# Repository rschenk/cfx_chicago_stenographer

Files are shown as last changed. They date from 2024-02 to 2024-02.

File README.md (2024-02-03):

<!-- omit from toc -->
# Chicago Stenographer Keycaps - Optimized for JLCPCB 3D printing

### The purpose of this fork

This fork resizes the Chicago Stenographer keycaps to be the same size as the quirky Chosfox CFX keycaps (16.5x16.5mm). The original CS keycaps are the standard "choc size" of 17.5x16.5mm, so the keycaps in this fork are 1mm narrower in width. 

Why? Because I designed my [Tern keyboard](https://github.com/rschenk/tern) spaced for CFX keycaps, mostly because I had them lying around and why not. Now I love that keyboard and wanted some Chicago Steno caps for it.

### Prior forks

This is forked from [infused-kim/kb_keycaps_chicago_stenographer](https://github.com/infused-kim/kb_keycaps_chicago_stenographer), which combines multiple chicago stenographer keycaps with sprues into one file to get around the $1 minimum charge of JLCPCB.

If you like these keycaps after trying the 3D printed version, [consider buying original versions from the creator at asymplex.xyz](https://www.asymplex.xyz).

### Printing at JLC

I have successfully printed multiple batches of these keycaps at JLC using the MJF process described below and they came out good. One batch, the stems were a little bit oversized, but a few scrapes with an X-Acto knife and they fit in the switches perfectly. The other batches fit great right out of the box. I'm typing on them right now.

<!-- omit from toc -->
## Table Of Contents

1. [Photos](#photos)
    1. [Render](#render)
    2. [Real Life](#real-life)
2. [About this fork](#about-this-fork)
3. [Documentation](#documentation)
    1. [Keycap Types](#keycap-types)
        1. [R2 Keycaps - Top](#r2-keycaps---top)
        2. [R3 Keycaps - Middle rows and home row](#r3-keycaps---middle-rows-and-home-row)
        3. [R4 Keycaps - Bottom](#r4-keycaps---bottom)
        4. [Thumb Keycaps](#thumb-keycaps)
        5. [1.5u Thumb Key](#15u-thumb-key)
        6. [Convex Keycaps](#convex-keycaps)
        7. [Lateral Keycaps](#lateral-keycaps)
    2. [What to print...](#what-to-print)
        1. [If you have a 5x3 row board (Such as the corne without the outer coulmn)](#if-you-have-a-5x3-row-board-such-as-the-corne-without-the-outer-coulmn)
        2. [If you have a 6x3 row board (Such as the corne WITH the outer coulmn)](#if-you-have-a-6x3-row-board-such-as-the-corne-with-the-outer-coulmn)
        3. [If you have a 6x4 board with a num row...](#if-you-have-a-6x4-board-with-a-num-row)
    3. [How to order on JLCPCB](#how-to-order-on-jlcpcb)
        1. [JLCPCB Shopping Cart Example](#jlcpcb-shopping-cart-example)
    4. [How to create custom sets of keycaps](#how-to-create-custom-sets-of-keycaps)

## Photos

### Render

Subtly sculpted choc spaced low profile
CS

### Real Life

This photo is from the creator's repo. It's not a JLCPCB print.

Look

## About this fork

This is a fork of [sporkus/PseudoMakeMeKeyCapProfiles](https://github.com/sporkus/PseudoMakeMeKeyCapProfiles/), which is a fork of [pseudoku's original chicago stenographer keycaps](https://github.com/pseudoku/PseudoMakeMeKeyCapProfiles).

Sporkus is the one who came up with the idea and the code to add spuers to the keycaps.

I expanded on those efforts in the following ways...

* Added support to generate rows of varying keycaps
* Fixed the 1.5u inner thumb key that is used in many corne-like boards
* Added the homing bar option to the lateral keys
* Added documentation on how to print the keycaps
* Fixed openscad warnings

Screenshot of thumbs stl

## Documentation

### Keycap Types

When I first started looking into these keycaps, I was incredibly confused by all the available keycap variations and files.

This repo is my attempt to simplify and document what I learned.

In the MX keycap world Rx is used to refer to rows and keycap heights. As someone who was only using Choc keycaps in the ergo keyboard world that was not intuitive for me at all.

But this graphic [from melgeek](https://www.melgeek.com/blogs/guide/the-type-of-keycaps-profiles) explains it well:
Keycap Rows

#### R2 Keycaps - Top

You use these keycaps for the top row, but for the CS keycap set, both R2 and R4 are the same. You simply flip them around.

I also included pre-rotated keycaps as R4, but you can also just print R2 twice.

If your keyboard has a num row, you would use them for the num row and the bottom alpha row.

If you have a corne-style keyboard with just three rows, you would use it for the top and bottom alpha rows.

#### R3 Keycaps - Middle rows and home row

You use these keycaps for the columns between the top and bottom rows.

If you have a num row, you would use it for the top alpha row and the homerow.

If you have a corne-style keyboard with just three rows, you would use it just for the home row.

#### R4 Keycaps - Bottom

As explained in the R2 section, these are exactly the same as the R2 files, but pre-rotated.

You can order 2x R2 or 1x R2 + 1x R4.

#### Thumb Keycaps

The thumb keycaps are designed to create a "dish" with ridges on the outer thumb keys.

The same model is used for the left and right keys, but it is mirrored. In this repo you will find a model that already has all the versions you will need.

If you have a corne-style thumb cluster with 3 keys, you can use a convex key for the middle one. It will act like a homing key.

And there is an alternative convex key included, which is slightly lower so that you can see which one you like better.

#### 1.5u Thumb Key

Additionally, there are also 1.5u variations of the outer thumb keys.

You have to be very careful if you get the files from other repos, because by default the stem is rotated by 90 degrees unlike regular 1.5u keys.

The files here have the stem in the correct orientation for keyboards like the corne where the switch is already rotated by 90 degrees.

#### Convex Keycaps

The convex keys are used on the middle thumb keys, but can also optionally be used on the inner and outer columns.

You can [see an example of how that looks here](https://www.printables.com/model/158865-chicago-steno-low-profile-ergo-keycaps).

#### Lateral Keycaps

Steno keycaps have vertical ridges that keep your finger aligned in the row. This is great, but some people prefer to not have these ridges for the inner and outer columns so that they don't have to lift the finger to reach the side-key or to perform horizontal combos with one finger.

Keep in mind, that the lateral keycaps are used as a pair on two columns next to each other.

The file contains only one set of the two. If you want it on both sides of the keyboard, you have to print it twice.

I suggest printing one version with the homing dots and another with the homing bars to get all possible variations.

### What to print...

You can find all files in the stl directory. You can also look at the `export_cs_*.scad` files to see what key models were used and further comments on how to use the sets.

#### If you have a 5x3 row board (Such as the corne without the outer coulmn)

* 1x `cs_row_r2_top.stl`
* 1x `cs_row_r3_homerow_bar.stl` or `cs_row_r3_homerow_dots.stl` (different homing keys)
  * Or the `cs_row_r3_regular.stl` and `cs_row_r3_homing_only.stl` to get both homing key variations
* 1x `cs_row_r4_bottom.stl`
* 1x `cs_row_thumbs.stl`

#### If you have a 6x3 row board (Such as the corne WITH the outer coulmn)

All of the above, PLUS...

* 1x `cs_column_regular.stl` or `cs_column_convex.stl` for the outer pinky column

You can also print the `cs_column_regular_with_homing_bars.stl` variation which contains two more homing key.

Combine it with the `cs_row_r3_homerow_dots.scad` to get both homing key variations without needing to print them separately.

Alternatively, you can also consider the lateral variation, but this one needs to be printed twice as it should be used on both the outer and pinky keys.

The leeve rows can also be used for the index and inner column as the stl includes homing key variations.

To be able to use lateral keys on both sides and get both types of homing keys you should print...

* 1x `cs_column_lateral_homing_bar.stl`
* 1x `cs_column_lateral_homing_dot.stl`

#### If you have a 6x4 board with a num row...

All of the above, PLUS...

* 1x `cs_row_r3_regular.stl` for the top alpha row (the r2 keycaps will be used for the num row)

### How to order on JLCPCB

* Upload the stl model
* Select 3D Technology: `MJF (Nylon)`
* Select Material: `PA12-HP Nylon`
* Optionally select Surface Finish: `Add - Dyeing - Dyed Black` to get black keycaps.
  * Without this they will be a "textured gray"
* Make sure to select the correct Quantity

The total for a 6x4 board with all the optional stuff will cost $23.88 + shipping.

> **Warning**
> You will likely get warnings that some areas on the 1.5u thumb keys are too thin.
>
> The original code for the 1.5u thumb keys produced keycaps with the wrong stem orientation. I have attempted to fix this problem, but JLCPCB still complains about areas that are too thin and will ask you if you want to take the risk of them not getting printed correctly when you order.
>
> All other keycaps should not have problems though.
>
> I have accepted the risk and will update this message once I receive the keycaps.

#### JLCPCB Shopping Cart Example

JLCPCB Shopping Cart Example

### How to create custom sets of keycaps

* Install OpenSCAD
  * The [snaphot version](https://openscad.org/downloads.html#snapshots) is recommended for performance reasons
  * If it crashes, [try an older version of the snapshot](https://files.openscad.org/snapshots/)
* Set up the dev environment
  * Adjust the Makefile with the path to your OpenSCAD installation
  * Unzip the `libraries.zip` into your [OpenSCAD library path](https://en.wikibooks.org/wiki/OpenSCAD_User_Manual/Libraries)
* Create your keycap set
  * Copy one of the files starting with `export_`
  * Adjust the keycaps you want to use. Available options are in `gen_sprued_keycaps.scad`
  * Keep in mind that jlcpcb only allows a maximum of 10 keycaps per file
* Generate STLs
  * Run `make` and it will generate all missing STLs
  * Alternatively you can also select which file to generate by running something like `make stl/cs_row_thumbs.stl`, but keep in mind that you have to use the file name of the final stl file and not of the source `.scad` file

Alternatively you can also run the GUI version, but it's a bit slow.

You can speed it up by enabling the `manifold` options in `Preferences -> Features` (Snapshot version only).

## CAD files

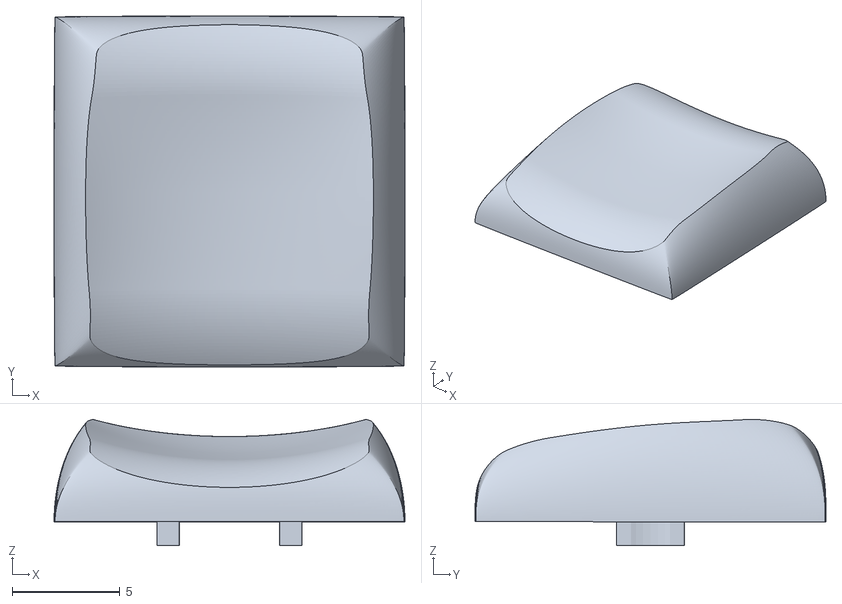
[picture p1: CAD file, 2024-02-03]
stl/single_keys/cs_r2_1.stl
16.3 x 16.3 x 5.86

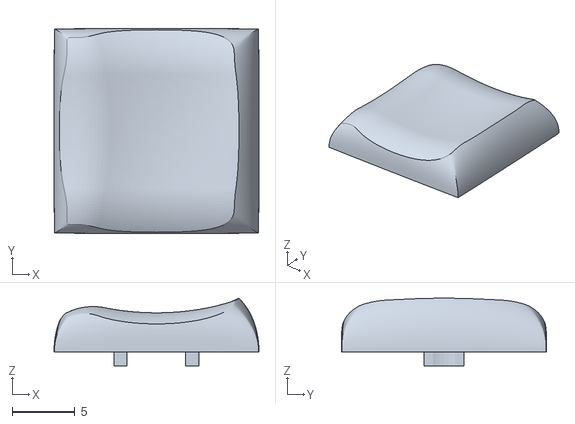
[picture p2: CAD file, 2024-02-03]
stl/single_keys/cs_r3_lateral_r.stl
16.3 x 16.3 x 5.38

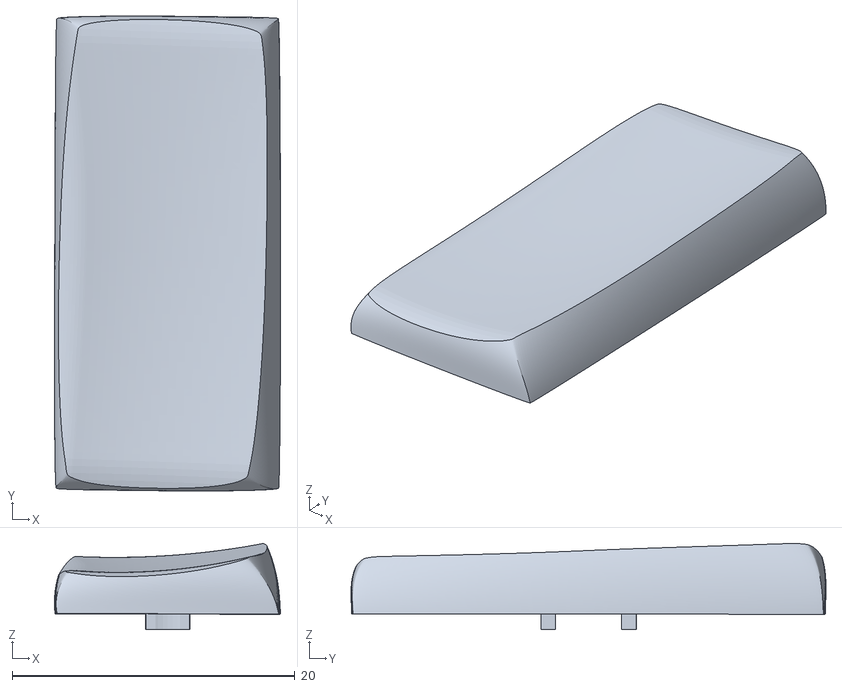
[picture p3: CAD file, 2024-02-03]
stl/single_keys/cs_t_2_r.stl
16.0 x 33.6 x 6.08

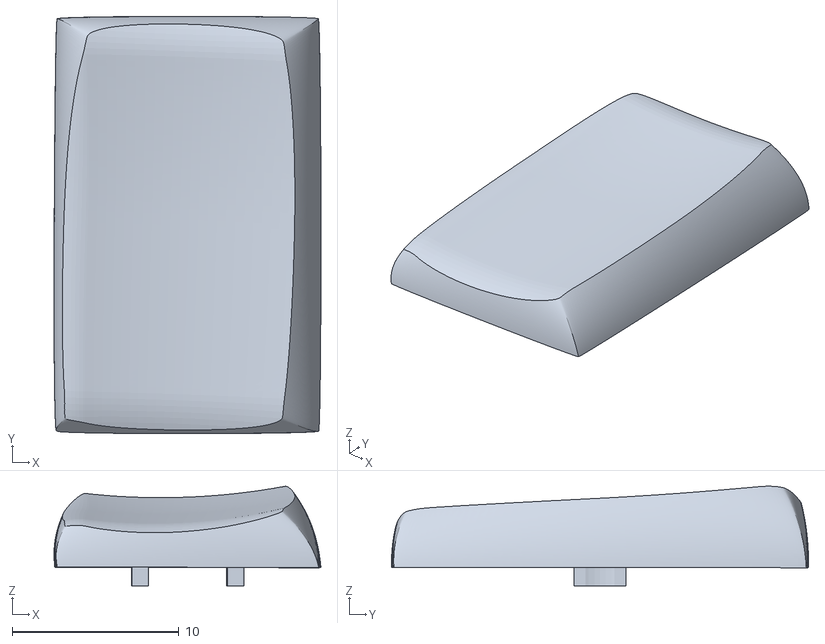
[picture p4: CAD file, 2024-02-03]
stl/single_keys/cs_t_stem_rot_15_r.stl
16.0 x 25.0 x 5.97

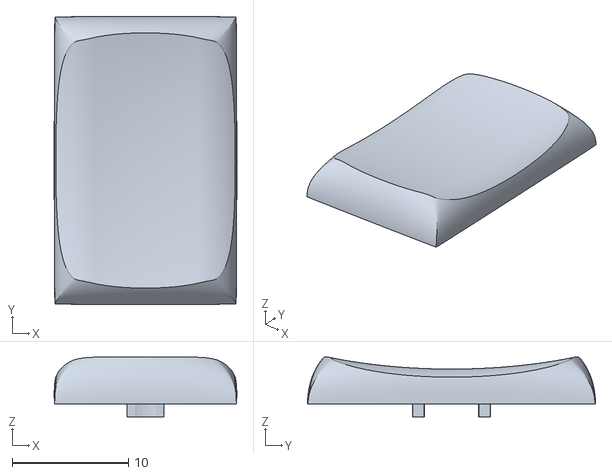
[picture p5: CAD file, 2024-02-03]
stl/single_keys/cs_r3_15.stl
15.7 x 24.8 x 5.15

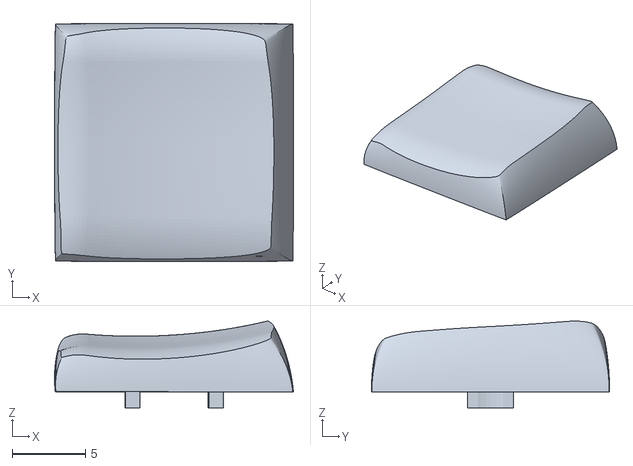
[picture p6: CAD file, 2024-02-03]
stl/single_keys/cs_t_1_r.stl
16.4 x 16.3 x 5.95

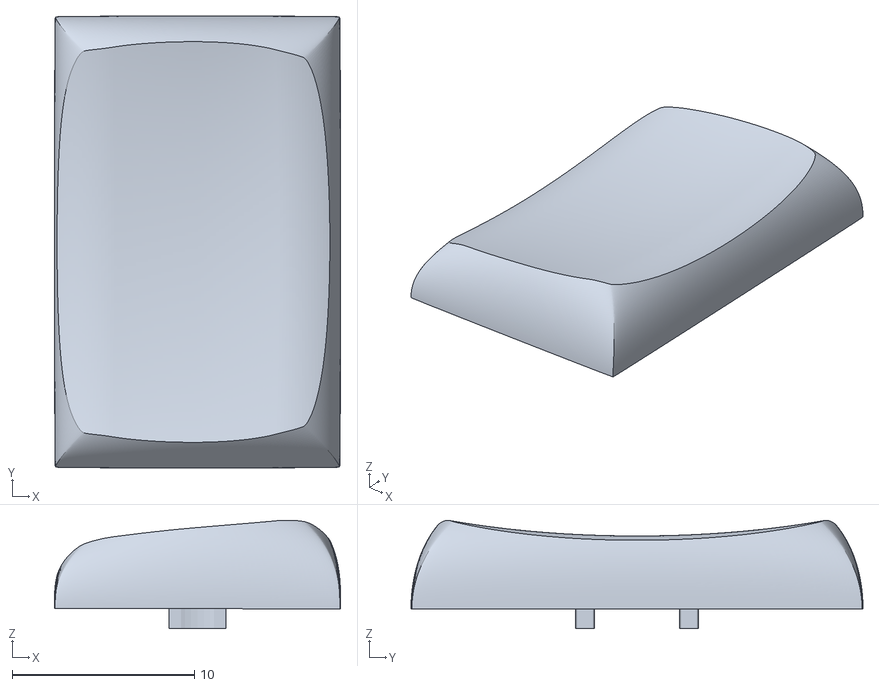
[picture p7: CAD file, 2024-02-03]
stl/single_keys/cs_r2_15.stl
15.7 x 24.8 x 5.95

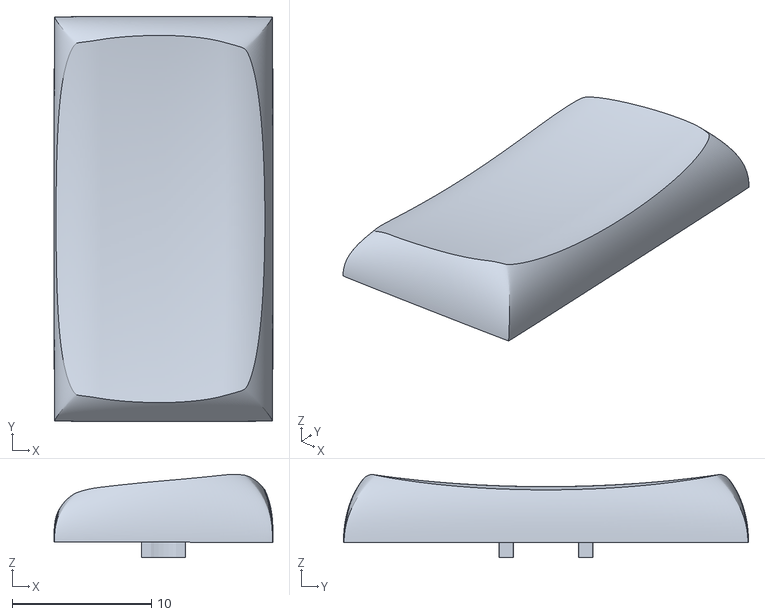
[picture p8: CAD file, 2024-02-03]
stl/single_keys/cs_r2_175.stl
15.7 x 29.0 x 5.96

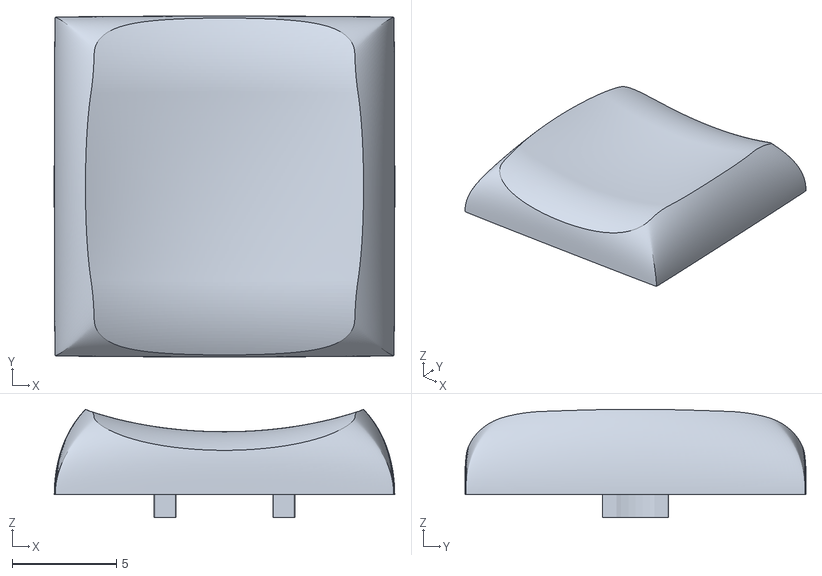
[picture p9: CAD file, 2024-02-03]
stl/single_keys/cs_r3_1.stl
16.3 x 16.3 x 5.19

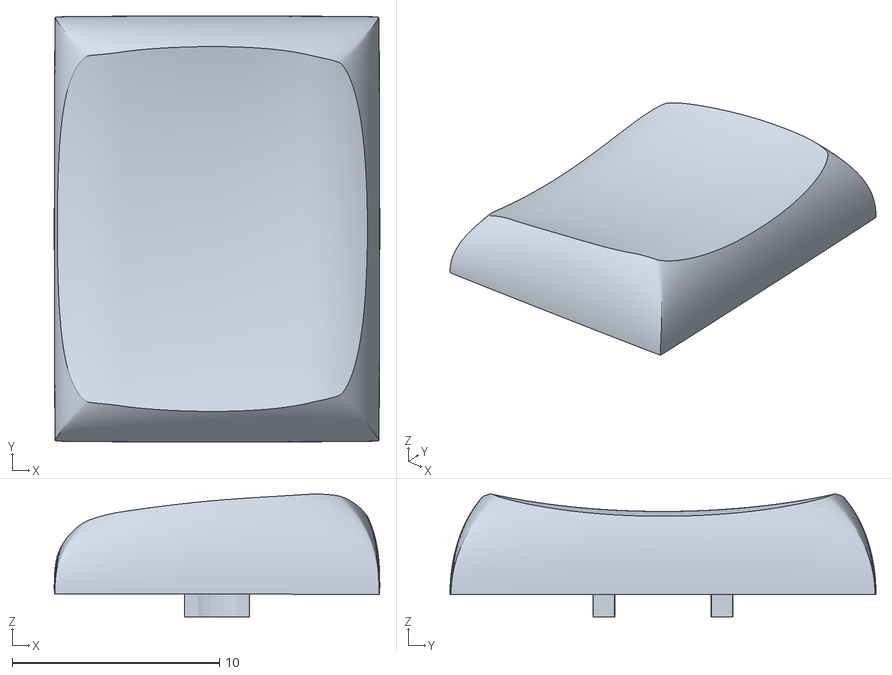
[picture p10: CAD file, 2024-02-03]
stl/single_keys/cs_r2_125.stl
15.7 x 20.5 x 5.93

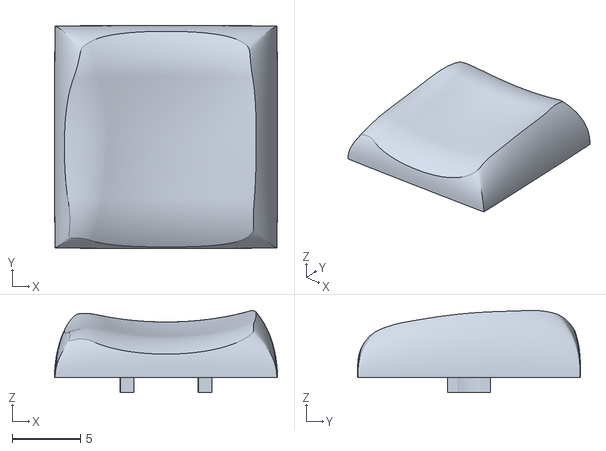
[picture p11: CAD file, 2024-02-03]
stl/single_keys/cs_r2_lateral_r.stl
16.3 x 16.3 x 6.01

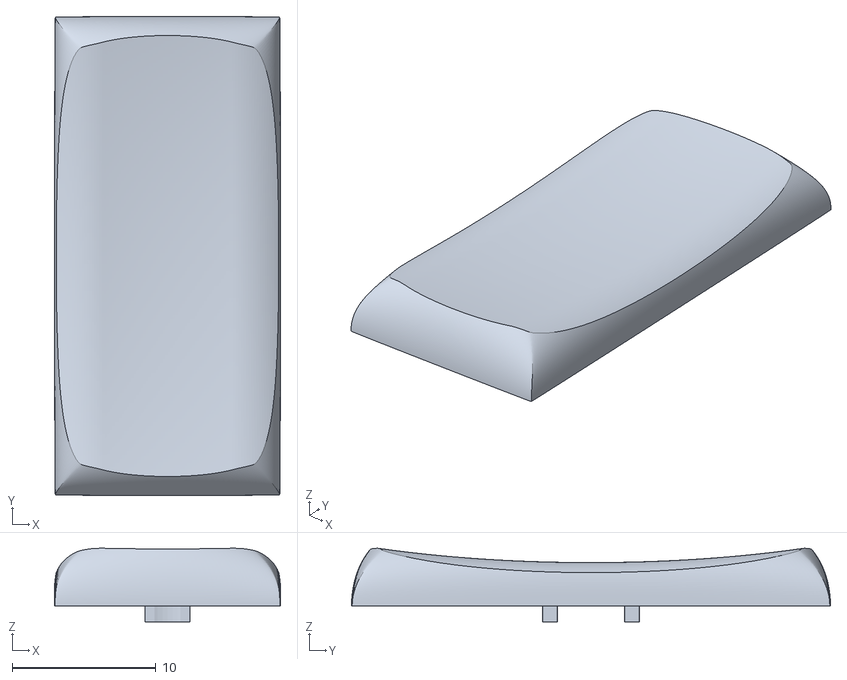
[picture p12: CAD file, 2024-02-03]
stl/single_keys/cs_r3_2.stl
15.7 x 33.3 x 5.12

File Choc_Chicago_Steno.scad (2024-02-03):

use <scad-utils/morphology.scad> //for cheaper minwoski
use <scad-utils/transformations.scad>
use <scad-utils/shapes.scad>
use <scad-utils/trajectory.scad>
use <scad-utils/trajectory_path.scad>
use <sweep.scad>
use <skin.scad>
//use <z-butt.scad>

//Choc Chord version Chicago Stenographer

/*Tester */
keycap_cs(
  keyID  = 6, //change profile refer to KeyParameters Struct
  cutLen = 0, //Don't change. for chopped caps
  Stem   = true, //tusn on shell and stems
  StemRot = 0, //change stem orientation by deg
  Dish   = true, //turn on dish cut
  Stab   = 0,
  visualizeDish = false, // turn on debug visual of Dish
  crossSection  = false, // center cut to check internal
  homeDot = false, //turn on homedots,
  homeBar = true, //turn on homebar,
  Legends = false
  );

//-Parameters
wallthickness = 1.1; // 1.75 for mx size, 1.1
topthickness = 3.0; //2 for phat 3 for chicago
stepsize = 50;  //resolution of Trajectory
step = 0.5;       //resolution of ellipes
fn = 60;          //resolution of Rounded Rectangles: 60 for output
layers = 50;    //resolution of vertical Sweep: 50 for output

//---Stem param
slop    = 0.3;
stemRot = 0;
stemWid = 8;
stemLen = 6;
stemCrossHeight = 1.8;
extra_vertical = 0.6;
stemLayers = 50; //resolution of stem to cap top transition
//#cube([18.16, 18.16, 10], center = true); // sanity check border

//injection param
draftAngle = 0; //degree  note:Stem Only
//TODO: Add wall thickness transition?


keyParameters = //keyParameters[KeyID][ParameterID]
[
//  BotWid, BotLen, TWDif, TLDif, keyh, WSft, LSft  XSkew, YSkew, ZSkew, WEx, LEx, CapR0i, CapR0f, CapR1i, CapR1f, CapREx, StemEx
    //Column 0
    //Levee: Chicago in choc Dimension
    [16.20,  16.20,   5.6, 	   5,  4.9,    0,   .0,     5,    -0,    -0,   2, 2.5,    .10,      2,     .10,      3,     2,       2], //Chicago Steno R2/R4
    [16.20,  16.20,   5.6, 	   5,  4.5,    0,   .0,     0,    -0,    -0,   2, 2.5,    .10,      3,     .10,      3,     2,       2], //Chicago Steno R3 flat
    [16.20,  16.20,  1.25, 	1.25,  4.5,    0,   .0,     0,    -0,    -0,   2, 2.5,    .10,     .5,     .10,     .5,     2,       2], //Chicago Steno R3 chord
    //mods 3
    [16.20,  16.20,  4.25, 	3.25,  5.5,  -.7,  0.7,     0,    -4,    -0,   2,   2,    .10,      2,     .10,      2,     2,       2], //Levee Corner R2
    [16.20,  16.20,  4.25, 	3.25,  5.2,  -.8,  0.6,     0,    -4,    -0,   2,   3,    .10,      2,     .10,      2,     2,       2], //Levee Corner R2
    //1.25: [5, 6]
    [20.45,  15.60,  5.6, 	   5,  4.9,    0,   .0,     5,    -0,    -0,   2, 2.5,     .1,      2,      .1,      3,     2,       2], //Chicago Steno R2/R4 1.25u
    [20.45,  15.60,  5.6, 	   5,  4.5,    0,   .0,     0,    -0,    -0,   2, 2.5,     .1,      3,      .1,      3,     2,       2], //Chicago Steno R3 1.25u
    //1.5: [7, 8]
    [24.70,  15.60,   5.6, 	   5,  4.9,    0,   .0,     5,    -0,    -0,   2, 2.5,     .1,      2,      .1,      3,     2,       2], //Chicago Steno R2/R4 1.5
    [24.70,  15.60,   5.6, 	   5,  4.5,    0,   .0,     0,    -0,    -0,   2, 2.5,     .1,      3,      .1,      3,     2,       2], //Chicago Steno R3 1.5u
    //1.75: [9, 10]
    [28.95,  15.60,   5.6, 	   5,  4.9,    0,   .0,     5,    -0,    -0,   2, 2.5,     .1,      2,      .1,      3,     2,       2], //Chicago Steno R2/R4 1.5
    [28.95,  15.60,   5.6, 	   5,  4.5,    0,   .0,     0,    -0,    -0,   2, 2.5,     .1,      3,      .1,      3,     2,       2], //Chicago Steno R3 1.5u
    //2.00: [11, 12]
    [33.20,  15.60,   5.6, 	   5,  4.9,    0,   .0,     5,    -0,    -0,   2, 2.5,     .1,      2,      .1,      3,     2,       2], //Chicago Steno R2/R4 1.5
    [33.20,  15.60,   5.6, 	   5,  4.5,    0,   .0,     0,    -0,    -0,   2, 2.5,     .1,      3,      .1,      3,     2,       2], //Chicago Steno R3 1.5u
    //2.25: [13, 14]
    [37.45,  15.60,   5.6, 	   5,  4.9,    0,   .0,     5,    -0,    -0,   2, 2.5,     .1,      2,      .1,      3,     2,       2], //Chicago Steno R2/R4 1.5
    [37.45,  15.60,   5.6, 	   5,  4.5,    0,   .0,     0,    -0,    -0,   2, 2.5,     .1,      3,      .1,      3,     2,       2], //Chicago Steno R3 1.5u
    // Ergo shits
    [18.75,  18.75,   5.6, 	   5,    8,    0,   .25,     0,    -0,    -0,   2, 2.5,    .10,      3,     .10,      3,     2,       2], //highpro 19.05 R2|4
    [17.20,  16.00,   5.6, 	   5,  4.7,    0,   .0,      3,    -0,    -0,   2, 2.5,    .10,      2,     .10,      3,     2,       2], //Chicago Steno R2 ALT
    [17.20,  16.00,   5.6, 	   5,  5.5,    0,   .0,      7,    -0,    -0,   2, 2.5,    .10,      2,     .10,      3,     2,       2], //Chicago Steno R1 Steap
    [17.20,  16.00,   5.6, 	   5,  7.0,    0,   .0,     10,    -0,    -0,   2, 2.5,    .10,      2,     .10,      3,     2,       2] //Chicago Steno R1 mild with alt R2
];

dishParameters = //dishParameter[keyID][ParameterID]
[
//FFwd1 FFwd2 FPit1 FPit2  DshDep DshHDif FArcIn FArcFn FArcEx     BFwd1 BFwd2 BPit1 BPit2  BArcIn BArcFn BArcEx
  //Column 0
  [ 4.5,    4,    7,  -50,      7,    1.7,   11.5,    17.5,     2,      4.5,    4,    2,   -35,   11.5,  15,     2], //Chicago Steno R2/R4
  [ 4.5,    4,    5,  -40,      7,    1.7,   11.5,    15,     2,      4.5,    4,    5,   -40,   11.5,    15,     2], //Chicago Steno R3 flat
  [ 4.5,    4,    5,  -40,      7,    1.7,   11.5,    15,     2,      4.5,    4,    5,   -40,   11.5,    15,     2], //Chicago Steno R3 chord

  [   6,  3.5,    7,  -50,      5,    1.0,   16,    23,     2,        6,  3.5,    7,   -50,   16,    23,     2], //Levee Steno R2/R4
  [   6,  3.5,    7,  -50,      5,    1.0,   16,    23,     2,        6,  3.5,    7,   -50,   16,    23,     2], //Levee Steno R2/R4
  //1.25
  [ 4.5,    4,    7,  -40,      8,    1.7,   16.0,  22.5,     2,      4.5,    4,    2,   -35,   16.0,  19.5,     2], //Chicago Steno R2/R4
  [ 4.5,    4,    5,  -40,      8,    1.7,   16.0,  19.5,     2,      4.5,    4,    5,   -40,   16.0,  19.5,     2], //Chicago Steno R3
  //1.5
  [ 4.5,    4,    7,  -40,      8,    1.7,   20.5,  26.5,     2,      4.5,    4,    2,   -35,   20.5,  24.0,     2], //Chicago Steno R2/R4
  [ 4.5,    4,    5,  -40,      8,    1.7,   20.5,  24.0,     2,      4.5,    4,    5,   -40,   20.5,  24.0,     2], //Chicago Steno R3
  //1.75
  [ 4.5,    4,    7,  -40,      8,    1.7,   25.0,  31.0,     2,      4.5,    4,    2,   -35,   25.0,  28.5,     2], //Chicago Steno R2/R4
  [ 4.5,    4,    5,  -40,      8,    1.7,   25.0,  28.5,     2,      4.5,    4,    5,   -40,   25.0,  28.5,     2], //Chicago Steno R3
  //2.00
  [ 4.5,    4,    7,  -40,      8,    1.7,   29.5,  35.5,     2,      4.5,    4,    2,   -35,   29.5,  33.0,     2], //Chicago Steno R2/R4
  [ 4.5,    4,    5,  -40,      8,    1.7,   29.5,  33.0,     2,      4.5,    4,    5,   -40,   29.5,  33.0,     2], //Chicago Steno R3
  //2.25
  [ 4.5,    4,    7,  -40,      8,    1.7,   33.0,  39.0,     2,      4.5,    4,    2,   -35,   33.0,  36.5,     2], //Chicago Steno R2/R4
  [ 4.5,    4,    5,  -40,      8,    1.7,   33.0,  36.5,     2,      4.5,    4,    5,   -40,   33.0,  36.5,     2], //Chicago Steno R3

  [   5,    5,    5,  -40,      7,    1.7,   11,    15,     2,        5,    5,    5,   -40,   11,    15,     2], //Chicago Steno R3 flat
  [ 4.5,    4,    7,  -50,      7,    1.7,   11,    17,     2,      4.5,    4,    2,   -35,   11,    15,     2], //Chicago Steno R1
  [ 4.5,    4,    7,  -50,      7,    1.7,   11,    17,     2,      4.5,    4,    2,   -35,   11,    15,     2], //Chicago Steno R1
  [ 4.5,    4,    7,  -50,      7,    1.7,   11,    17,     2,      4.5,    4,    2,   -35,   11,    15,     2] //Chicago Steno R1
];


function BottomWidth(keyID)  = keyParameters[keyID][0];  //
function BottomLength(keyID) = keyParameters[keyID][1];  //
function TopWidthDiff(keyID) = keyParameters[keyID][2];  //
function TopLenDiff(keyID)   = keyParameters[keyID][3];  //
function KeyHeight(keyID)    = keyParameters[keyID][4];  //
function TopWidShift(keyID)  = keyParameters[keyID][5];
function TopLenShift(keyID)  = keyParameters[keyID][6];
function XAngleSkew(keyID)   = keyParameters[keyID][7];
function YAngleSkew(keyID)   = keyParameters[keyID][8];
function ZAngleSkew(keyID)   = keyParameters[keyID][9];
function WidExponent(keyID)  = keyParameters[keyID][10];
function LenExponent(keyID)  = keyParameters[keyID][11];
function CapRound0i(keyID)   = keyParameters[keyID][12];
function CapRound0f(keyID)   = keyParameters[keyID][13];
function CapRound1i(keyID)   = keyParameters[keyID][14];
function CapRound1f(keyID)   = keyParameters[keyID][15];
function ChamExponent(keyID) = keyParameters[keyID][16];
function StemExponent(keyID) = keyParameters[keyID][17];
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

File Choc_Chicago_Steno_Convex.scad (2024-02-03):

use <scad-utils/morphology.scad> //for cheaper minwoski
use <scad-utils/transformations.scad>
use <scad-utils/shapes.scad>
use <scad-utils/trajectory.scad>
use <scad-utils/trajectory_path.scad>
use <sweep.scad>
use <skin.scad>
//use <z-butt.scad>

//NOTE: with sweep cuts, top surface may not be visible in review, it should be visible once rendered

mirror([0,0,0])keycap_cs_convex(
  keyID  = 2, //change profile refer to KeyParameters Struct
  cutLen = 0, //Don't change. for chopped caps
  Stem   = true, //tusn on shell and stems
  StemRot = 0,//change stem orientation by deg
  Dish   = true, //turn on dish cut
  Stab   = 0,
  visualizeDish = true, // turn on debug visual of Dish
  crossSection  = false, // center cut to check internal
  homeDot = false, //turn on homedots
  Legends = false
);

//Parameters
wallthickness = 1.2;
topthickness  = 2;   //
stepsize      = 50;  //resolution of Trajectory
step          = 1;   //resolution of ellipes
fn            = 60;  //resolution of Rounded Rectangles: 60 for output
layers        = 50;  //resolution of vertical Sweep: 50 for output
dotRadius     = 1.25;   //home dot size
//---Stem param
slop    = 0.25;
stemWid = 8;
stemLen = 6;
stemCrossHeight = 1.8;
extra_vertical  = 0.6;
StemBrimDep     = 0;
stemLayers      = 50; //resolution of stem to cap top transition
driftAngle      = 0;

keyParameters = //keyParameters[KeyID][ParameterID]
[
//  BotWid, BotLen, TWDif, TLDif, keyh, WSft, LSft  XSkew, YSkew, ZSkew, WEx, LEx, CapR0i, CapR0f, CapR1i, CapR1f, CapREx, StemEx
    //Column 0
    //Levee: Chicago in choc Dimension 0-3
    [16.20,  16.20,   5.6, 	   5,  3.8,    0,  -.5,     7,    -0,    -0,   2, 2,    .10,      3,     .10,      3,     2,       2], //Chicago Steno R2x 1u
    [16.20,  16.20,   5.6, 	   5,  4.4,    0,   .0,     0,    -0,    -0,   2, 2,    .10,      3,     .10,      3,     2,       2], //Chicago Steno R3x 1u

    // R3x 1.25~2.25u [4:8]
    [20.45,  15.60,   5.6, 	   5.6,  4.5,   0,   .0,   0,    -0,    -0,   2, 2.5,   .1,      3,     .1,      3,     2,       2], //Chicago Steno R3x 1.25u
    [24.70,  15.60,   5.6, 	   5.6,  4.5,   0,   .0,   0,    -0,    -0,   2, 2.5,   .1,      3,     .1,      3,     2,       2], //Chicago Steno R3x 1.5u
    [28.95,  15.60,   5.6, 	   5.6,  4.5,   0,   .0,   0,    -0,    -0,   2, 2.5,   .1,      3,     .1,      3,     2,       2], //Chicago Steno R3x 1.75u
    [33.20,  15.60,   5.6, 	   5.6,  4.5,   0,   .0,   0,    -0,    -0,   2, 2.5,   .1,      3,     .1,      3,     2,       2], //Chicago Steno R3x 2.0u
    [37.45,  15.60,   5.6, 	   5.6,  4.5,   0,   .0,   0,    -0,    -0,   2, 2.5,   .1,      3,     .1,      3,     2,       2], //Chicago Steno R3x 2.25u

//  original from pseudo, mislabled/ missing params?
//    [35.85,  15.65,     7, 	   7,  4.4,    0,   .0,     0,    -0,    -0,   2, 2,    .30,      5,     .30,      5,     2,       2], //Chicago Steno R3x 2u
//    [35.85,  15.65,     7, 	   7,  4.4,    0,   .0,     0,    -0,    -0,   2, 2,    .30,      5,     .30,      5,     2,       2], //Chicago Steno R3x 2u
//    //mods 3
//    [17.20,  16.00,  4.25, 	3.25,  5.5,  -.7,  0.7,     0,    -4,    -0,   2,   2,    .10,      2,     .10,      2,     2,       2], //Levee Corner R2
//    [17.20,  16.00,  4.25, 	3.25,  5.2,  -.8,  0.6,     0,    -4,    -0,   2,   3,    .10,      2,     .10,      2,     2,       2], //Levee Corner R2
//    //1.25 5
//    [21.3,   15.60,  5.6, 	   5,  4.5,    0,   .0,     5,    -0,    -0,   2,   2,     .5,      3,      .5,      3,     2,       2], //Chicago Steno R2/R4 1.25u
//    [21.4,   15.60,  5.6, 	   5,  4.5,    0,   .0,     0,    -0,    -0,   2,   2,     .5,      3,      .5,      3,     2,       2], //Chicago Steno R3 1.25u
//    //1.5 7
//    [26.15,  15.60,   5.6, 	   5,  4.5,    0,   .0,     5,    -0,    -0,   2,   2,     .5,      3,      .5,      3,     2,       2], //Chicago Steno R2/R4 1.5
//    [26.15,  15.60,   5.6, 	   5,  4.5,    0,   .0,     0,    -0,    -0,   2,   2,     .5,      3,      .5,      3,     2,       2], //Chicago Steno R3 1.5u
//    //1.75 9
//    [30.90,  15.60,   5.6, 	   5,  4.5,    0,   .0,     5,    -0,    -0,   2,   2,     .5,      3,      .5,      3,     2,       2], //Chicago Steno R2/R4 1.5
//    [30.90,  15.60,   5.6, 	   5,  4.5,    0,   .0,     0,    -0,    -0,   2,   2,     .5,      3,      .5,      3,     2,       2], //Chicago Steno R3 1.5u
//    // Ergo shits
//    [18.75,  18.75,   5.6, 	   5,    8,    0,   .25,     0,    -0,    -0,   2, 2.5,    .10,      3,     .10,      3,     2,       2], //highpro 19.05 R2|4
//    [17.20,  16.00,   5.6, 	   5,  4.7,    0,   .0,      3,    -0,    -0,   2, 2.5,    .10,      2,     .10,      3,     2,       2], //Chicago Steno R2 ALT
//    [17.20,  16.00,   5.6, 	   5,  5.5,    0,   .0,      7,    -0,    -0,   2, 2.5,    .10,      2,     .10,      3,     2,       2], //Chicago Steno R1 Steap
//    [17.20,  16.00,   5.6, 	   5,  7.0,    0,   .0,     10,    -0,    -0,   2, 2.5,    .10,      2,     .10,      3,     2,       2], //Chicago Steno R1 mild with alt R2
];

dishParameters = //dishParameter[keyID][ParameterID]
[
//FFwd1 FFwd2 FPit1    FPit2  DshDepi    DshHDif FArcIn  FArcFn FArcEx  BFwd1 BFwd2 BPit1 BPit2  BArcIn BArcFn BArcEx
  [   5,  2.3,    2,     -55,    1.5,    3.75,     8.5,    8.5,    2,      5,    3,    2,  -50,    8.5,    8.7 ,     2], //R2x 1u
  [ 4.5,  3.3,   -3,     -45,    1.5,    3.75,     8.5,    8.7,    2,    4.5,  3.3,   -3,  -45,    8.5,   8.7,     2], //R3x 1u

  // R3x 1.25~2.25u [4:8]
  [ 4.5,  3.2,   -7,     -45,    1.5,    3.75,    10.75,   10.95,  2,    4.5,  3.2,   -7,  -45,   10.75,   10.95,  2], //R3x 1.25u
  [ 4.5,  3.2,   -7,     -45,    1.5,    3.75,    13.00,   13.20,  2,    4.5,  3.2,   -7,  -45,   13.00,   13.20,  2], //R3x 1.5u
  [ 4.5,  3.2,   -7,     -45,    1.5,    3.75,    15.25,   15.45,  2,    4.5,  3.2,   -7,  -45,   15.25,   15.45,  2], //R3x 1.75u
  [ 4.5,  3.2,   -7,     -45,    1.5,    3.75,    17.50,   17.70,  2,    4.5,  3.2,   -7,  -45,   17.50,   17.70,  2], //R3x 2.00u
  [ 4.5,  3.2,   -7,     -45,    1.5,    3.75,    19.75,   19.95,  2,    4.5,  3.2,   -7,  -45,   19.75,   19.95,  2], //R3x 2.25u

//  original from pseudo, mislabled/ missing params?
//  [ 4.5,  3.2,   -5,  -45,    1.5,   3.75,  19.0,    18,     2,     4.5,  3.2,   -5,  -45,   19.0,    18,     2], //R3x 2u
//  [ 4.5,  3.2,   -5,  -45,    1.5,   3.75,  19.0,    18,     2,     4.5,  3.2,   -5,  -45,   19.0,    18,     2], //R3x 2u
//  ---
//  [   4,  4.2,   -5,  -15,      1,      3,  18.2,    21,     2,       5,    3,   -5,  -15,   18.2,    21,     2], //R3 2u
//  [  4.,  1.5,    8,  -55,      3,      7,   9.0,     9,     2,       4,    3,    3,  -50,    9,     9,     2],  //R3
//  [  4.,  1.5,   -0,  -50,      3,      7,   9.0,     9,     2,       4,    3,    -10,  -50,    9,     9,     2],  //R3
//  [   5,  3.5,    8,  -50,      5,    1.8,   8.8,    15,     2,       6,    4,   13,   30,    8.8,    16,     2], //R1
];

function FrontForward1(keyID) = dishParameters[keyID][0];  //
function FrontForward2(keyID) = dishParameters[keyID][1];  //
function FrontPitch1(keyID)   = dishParameters[keyID][2];  //
function FrontPitch2(keyID)   = dishParameters[keyID][3];  //
function DishDepth(keyID)     = dishParameters[keyID][4];  //
function DishHeightDif(keyID) = dishParameters[keyID][5];  //
function FrontInitArc(keyID)  = dishParameters[keyID][6];
function FrontFinArc(keyID)   = dishParameters[keyID][7];
function FrontArcExpo(keyID)  = dishParameters[keyID][8];
function BackForward1(keyID)  = dishParameters[keyID][9];  //
function BackForward2(keyID)  = dishParameters[keyID][10];  //
function BackPitch1(keyID)    = dishParameters[keyID][11];  //
function BackPitch2(keyID)    = dishParameters[keyID][12];  //
function BackInitArc(keyID)   = dishParameters[keyID][13];
function BackFinArc(keyID)    = dishParameters[keyID][14];
function BackArcExpo(keyID)   = dishParameters[keyID][15];

function BottomWidth(keyID)  = keyParameters[keyID][0];  //
function BottomLength(keyID) = keyParameters[keyID][1];  //
function TopWidthDiff(keyID) = keyParameters[keyID][2];  //
function TopLenDiff(keyID)   = keyParameters[keyID][3];  //
function KeyHeight(keyID)    = keyParameters[keyID][4];  //
function TopWidShift(keyID)  = keyParameters[keyID][5];
function TopLenShift(keyID)  = keyParameters[keyID][6];
function XAngleSkew(keyID)   = keyParameters[keyID][7];
function YAngleSkew(keyID)   = keyParameters[keyID][8];
function ZAngleSkew(keyID)   = keyParameters[keyID][9];
function WidExponent(keyID)  = keyParameters[keyID][10];
function LenExponent(keyID)  = keyParameters[keyID][11];
function CapRound0i(keyID)   = keyParameters[keyID][12];
function CapRound0f(keyID)   = keyParameters[keyID][13];
function CapRound1i(keyID)   = keyParameters[keyID][14];
function CapRound1f(keyID)   = keyParameters[keyID][15];
function ChamExponent(keyID) = keyParameters[keyID][16];
function StemExponent(keyID) = keyParameters[keyID][17];
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

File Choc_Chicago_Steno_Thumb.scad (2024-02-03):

use <scad-utils/morphology.scad> //for cheaper minwoski
use <scad-utils/transformations.scad>
use <scad-utils/shapes.scad>
use <scad-utils/trajectory.scad>
use <scad-utils/trajectory_path.scad>
use <sweep.scad>
use <skin.scad>
//use <z-butt.scad>
// Choc Chord version Chicago Stenographer with sculpte Thumb cluter
// change stemrot

mirror([1,0,0])keycap_cs_thumb(
  keyID   = 3, //change profile refer to KeyParameters Struct
  cutLen  = 0, //Don't change. for chopped caps
  Stem    = true, //tusn on shell and stems
  StemRot = 90,//change stem orientation by deg
  Dish    = true, //turn on dish cut
  Stab    = 0,
  visualizeDish = false, // turn on debug visual of Dish
  crossSection  = false, // center cut to check internal
  homeDot = false, //turn on homedots
  homeBar = false, //turn on homebar
  Legends = false
);

//-Parameters
wallthickness = 1.1; // 1.75 for mx size, 1.1
topthickness = 2.5; //2 for phat 3 for chicago
stepsize = 40;  //resolution of Trajectory
step =2;       //resolution of ellipes
fn = 60;          //resolution of Rounded Rectangles: 60 for output
layers = 50;    //resolution of vertical Sweep: 50 for output

//---Stem param
slop    = 0.3;
stemWid = 8;
stemLen = 6;
stemCrossHeight = 1.8;
extra_vertical = 0.6;
stemLayers = 50; //resolution of stem to cap top transition
//#cube([18.16, 18.16, 10], center = true); // sanity check border

//injection param
draftAngle = 0; //degree  note:Stem Only
//TODO: Add wall thickness transition?

keyParameters = //keyParameters[KeyID][ParameterID]
[
//  BotWid, BotLen, TWDif, TLDif, keyh, WSft, LSft  XSkew, YSkew, ZSkew, WEx, LEx, CapR0i, CapR0f, CapR1i, CapR1f, CapREx, StemEx
    //Column 0
    //Levee: Chicago in choc Dimension for ref
    [16.20,  16.20,   5.6, 	   5,  5.0,    0,   .0,     5,    -0,    -0,   2, 2.5,    .10,      2,     .10,      3,     2,       2], //Levee Steno R2/R4
    [16.20,  16.20,   5.6, 	   5,  4.6,    0,   .0,     0,    -0,    -0,   2, 2.5,    .10,      3,     .10,      3,     2,       2], //Levee Steno R3
    //Thumb
    [16.20,  16.20,  4.25, 	3.25,  5.0,  -.5,  0.0,    -3,    -3,    -0,   2,   2,    .10,      2,     .10,      2,     2,       2], //Thumb 1
    [15.65,  24.70,   5.5, 	3.25,  4.9,  -.5,  0.0,    -3,    -2,    -2,   2,   2,     .3,      2,      .3,    2.5,     2,       2], //Thumb 1.5
    [15.65,  33.20,  4.25, 	3.25,  4.9, -.25,  0.0,    -2.5,    -4,    -2,   2,   3,     .3,      2,      .3,    2.5,     2,       2], //Thumb 2.0
    //1.25 5
    [20.45,   15.60,  5.6, 	   5,  4.5,    0,   .0,     5,    -0,    -0,   2,   2,     .5,      3,      .5,      3,     2,       2], //Chicago Steno R2/R4 1.25u
    [20.45,   15.60,  5.6, 	   5,  4.5,    0,   .0,     0,    -0,    -0,   2,   2,     .5,      3,      .5,      3,     2,       2], //Chicago Steno R3 1.25u
    //1.5 7
    [24.70,  15.60,   5.6, 	   5,  4.5,    0,   .0,     5,    -0,    -0,   2,   2,     .5,      3,      .5,      3,     2,       2], //Chicago Steno R2/R4 1.5
    [24.70,  15.60,   5.6, 	   5,  4.5,    0,   .0,     0,    -0,    -0,   2,   2,     .5,      3,      .5,      3,     2,       2], //Chicago Steno R3 1.5u
    //1.75 9
    [28.95,  15.60,   5.6, 	   5,  4.5,    0,   .0,     5,    -0,    -0,   2,   2,     .5,      3,      .5,      3,     2,       2], //Chicago Steno R2/R4 1.5
    [28.95,  15.60,   5.6, 	   5,  4.5,    0,   .0,     0,    -0,    -0,   2,   2,     .5,      3,      .5,      3,     2,       2], //Chicago Steno R3 1.5u
    // Ergo shits
    [18.75,  18.75,   5.6, 	   5,    8,    0,   .25,     0,    -0,    -0,   2, 2.5,    .10,      3,     .10,      3,     2,       2], //highpro 19.05 R2|4
    [17.20,  16.00,   5.6, 	   5,  4.7,    0,   .0,      3,    -0,    -0,   2, 2.5,    .10,      2,     .10,      3,     2,       2], //Chicago Steno R2 ALT
    [17.20,  16.00,   5.6, 	   5,  5.5,    0,   .0,      7,    -0,    -0,   2, 2.5,    .10,      2,     .10,      3,     2,       2], //Chicago Steno R1 Steap
    [17.20,  16.00,   5.6, 	   5,  7.0,    0,   .0,     10,    -0,    -0,   2, 2.5,    .10,      2,     .10,      3,     2,       2], //Chicago Steno R1 mild with alt R2

];

dishParameters = //dishParameter[keyID][ParameterID]
[
//FFwd1 FFwd2 FPit1 FPit2  DshDep DshHDif FArcIn FArcFn FArcEx     BFwd1 BFwd2 BPit1 BPit2  BArcIn BArcFn BArcEx FTani FTanf BTani BTanf TanEX PhiInit PhiFin
  //Column 0
  [ 4.5,    4,    7,  -50,      7,    1.7,   11,    17,     2,      4.5,    4,    2,   -35,   11,    15,     2,     3,  4.5,    3,  4.5,   2, 203, 210], //Chicago Steno R2/R4
  [ 4.5,    4,    5,  -40,      7,    1.7,   11,    15,     2,      4.5,    4,    5,   -40,   11,    15,     2,     4,    5,    4,    5,   2, 200, 210], //Chicago Steno R3 flat
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

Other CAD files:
stl/single_keys/cs_r3_lateral_l_dot.stl
stl/single_keys/cs_t_15_l.stl
stl/single_keys/cs_t_2_l.stl
stl/single_keys/cs_t_stem_rot_2_r.stl
stl/single_keys/cs_r2_225.stl
stl/single_keys/cs_t_stem_rot_15_l.stl
export_cs_row_thumbs.scad
gen_sprued_keycaps.scad
stl/single_keys/cs_r2_2.stl
stl/single_keys/cs_r2_lateral_l.stl
stl/single_keys/cs_r2x_1.stl
stl/single_keys/cs_r3_125.stl
stl/single_keys/cs_r3_125_bar.stl
stl/single_keys/cs_r3_125_dot.stl
stl/single_keys/cs_r3_175.stl
stl/single_keys/cs_r3_1_bar.stl
stl/single_keys/cs_r3_1_dot.stl
stl/single_keys/cs_r3_225.stl
stl/single_keys/cs_r3_lateral_l.stl
stl/single_keys/cs_r3_lateral_l_bar.stl
stl/single_keys/cs_r3_lateral_r_bar.stl
stl/single_keys/cs_r3_lateral_r_dot.stl
stl/single_keys/cs_r3x_1.stl
stl/single_keys/cs_r4_1.stl
stl/single_keys/cs_r4_lateral_l.stl
stl/single_keys/cs_r4_lateral_r.stl
stl/single_keys/cs_r4x_1.stl
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

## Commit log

2024-02-03 Chosfox CFX sized keys
    [Choc_Chicago_Steno.scad, Choc_Chicago_Steno_Convex.scad, Choc_Chicago_Steno_Thumb.scad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]
2024-02-03 3mm sprues as recommended by JLC
    [cs_r2_1.stl, cs_r2_125.stl, cs_r2_15.stl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]
